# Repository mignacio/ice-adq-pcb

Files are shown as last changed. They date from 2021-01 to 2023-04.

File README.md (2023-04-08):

# ice-adq-pcb

This printed circuit board is a Shield or Poncho for the EDU-CIAA board.
It is a datalogger for internal combustion engines, it has three digital thermocouple readout sensor.
One variable reluctance RPM sensor.
One Narrowband Lambda probe analog interface.
And a resistive oil pressure sensor analog interface.
It trasmits data over bluetooth via an HM-10 BLE module.

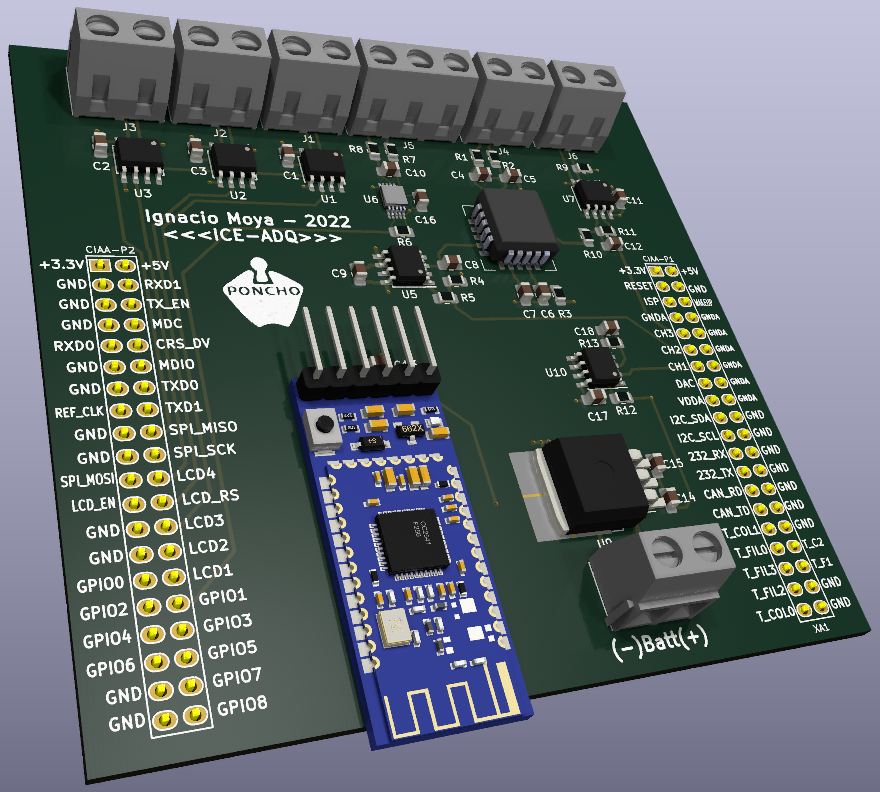
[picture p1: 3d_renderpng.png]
3d-render


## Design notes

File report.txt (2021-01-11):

Info: Backing up file "/home/freesbee/Ponchos/modelos/Basico/sym-lib-table" to file "/home/freesbee/Ponchos/modelos/Basico/rescue-backup/sym-lib-table-2020-12-31-14-45-42".
Info: Backing up file "/home/freesbee/Ponchos/modelos/Basico/basico.sch" to file "/home/freesbee/Ponchos/modelos/Basico/rescue-backup/basico-2020-12-31-14-45-42.sch".
Info: Backing up file "/home/freesbee/Ponchos/modelos/Basico/basico.pro" to file "/home/freesbee/Ponchos/modelos/Basico/rescue-backup/basico-2020-12-31-14-45-42.pro".
Info: Backing up file "/home/freesbee/Ponchos/modelos/Basico/basico-cache.lib" to file "/home/freesbee/Ponchos/modelos/Basico/rescue-backup/basico-cache-2020-12-31-14-45-42.lib".
Info: Backing up file "/home/freesbee/Ponchos/modelos/Basico/basico-rescue.lib" to file "/home/freesbee/Ponchos/modelos/Basico/rescue-backup/basico-rescue-2020-12-31-14-45-42.lib".
Info: Backing up file "/home/freesbee/Ponchos/modelos/Basico/basico-rescue.dcm" to file "/home/freesbee/Ponchos/modelos/Basico/rescue-backup/basico-rescue-2020-12-31-14-45-42.dcm".
Info: Adding library "basico", file "${KIPRJMOD}/lib/basico.lib" to project symbol library table.
Symbol "OSHWA" mapped to symbol library "basico".
Symbol "Logo_Poncho" mapped to symbol library "basico".
Symbol "+3.3V" mapped to symbol library "basico".
Symbol "+5V" mapped to symbol library "basico".
Symbol "PWR_FLAG" mapped to symbol library "basico".
Symbol "+5VP" mapped to symbol library "basico".
Symbol "Conn_Poncho2P_2x_20x2" mapped to symbol library "basico".
Symbol "Conn_Poncho2P_2x_20x2" mapped to symbol library "basico".
Symbol "GND" mapped to symbol library "basico".
Symbol "+3.3VP" mapped to symbol library "basico".
Symbol "+3.3VP" mapped to symbol library "basico".
Symbol "+3.3V" mapped to symbol library "basico".
Symbol "+5VP" mapped to symbol library "basico".
Symbol "+5V" mapped to symbol library "basico".
Symbol "GNDD" mapped to symbol library "basico".
Symbol "GNDD" mapped to symbol library "basico".
Symbol "GND" mapped to symbol library "basico".
Symbol "GNDA" mapped to symbol library "basico".
Symbol "GNDA" mapped to symbol library "basico".
Info: Symbol library table mapping complete!

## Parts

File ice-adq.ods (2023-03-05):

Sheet: ice-adq
Id | Designator | Package | Quantity | Designation | Supplier and ref
1 | XA1 | Conn_Poncho_SinBorde | 1 | Conn_Poncho2P_2x_20x2
2 | G*** | Logo_Poncho | 1 | LOGO
3 | C1,C2,C3,C4,C5,C6,C7,C8,C9,C11,C12,C13,C15,C16,C17,C18 | C_0805_2012Metric_Pad1.15x1.40mm_HandSolder | 16 | 0.01uF
4 | C10 | C_0805_2012Metric_Pad1.15x1.40mm_HandSolder | 1 | 1nF
5 | J1 | TerminalBlock_bornier-2_P5.08mm | 1 | T_AdmisiÃ³n
6 | J2 | TerminalBlock_bornier-2_P5.08mm | 1 | T_Escape
7 | J3 | TerminalBlock_bornier-2_P5.08mm | 1 | T_Aceite
8 | J4 | TerminalBlock_bornier-2_P5.08mm | 1 | Sonda Lambda
9 | J5 | TerminalBlock_bornier-3_P5.08mm | 1 | Sens. Inductivo
10 | J6 | TerminalBlock_bornier-2_P5.08mm | 1 | + PresiÃ³n
11 | J7 | TerminalBlock_bornier-2_P5.08mm | 1 | BATT
12 | R1,R2 | R_0805_2012Metric_Pad1.15x1.40mm_HandSolder | 2 | 100ohm
13 | R3,R6,R7,R8,R13 | R_0805_2012Metric_Pad1.15x1.40mm_HandSolder | 5 | 10k
14 | R4 | R_0805_2012Metric_Pad1.15x1.40mm_HandSolder | 1 | 1.1k
15 | R5 | R_0805_2012Metric_Pad1.15x1.40mm_HandSolder | 1 | 680
16 | R9,R10,R11 | R_0805_2012Metric_Pad1.15x1.40mm_HandSolder | 3 | R_US
17 | U1,U2,U3 | SOIC-8_3.9x4.9mm_P1.27mm | 3 | MAX31855
18 | U5,U7,U10 | SOIC-8_3.9x4.9mm_P1.27mm | 3 | LM358
19 | U6 | UMAX10 | 1 | MAX9924
20 | U4 | PLCC-20 | 1 | LM9044
21 | U9 | SOT-223 | 1 | L7805
22 | R12 | R_0805_2012Metric_Pad1.15x1.40mm_HandSolder | 1 | 39k
23 | C14 | C_0805_2012Metric_Pad1.15x1.40mm_HandSolder | 1 | 0.22uF
24 | U8 | PinHeader_1x06_P2.54mm_Vertical | 1 | hm-10-module

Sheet: BOM
Package | Quantity | Designation | Supplier and ref
C_0805_2012Metric_Pad1.15x1.40mm_HandSolder | 16 | 0.01uF | https://www.digikey.com/product-detail/en/C0805C153K5RAC7800/399-C0805C153K5RAC7800CT-ND/411436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
C_0805_2012Metric_Pad1.15x1.40mm_HandSolder | 1 | 1nF | No se consigue
C_0805_2012Metric_Pad1.15x1.40mm_HandSolder | 1 | 0.22uF | https://www.digikey.com/product-detail/en/C0805C223K5RAC7210/399-C0805C223K5RAC7210CT-ND/12701470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
R_0805_2012Metric_Pad1.15x1.40mm_HandSolder | 2 | 100ohm | https://www.digikey.com/en/products/detail/yageo/AC0805FR-10100RL/14286774
R_0805_2012Metric_Pad1.15x1.40mm_HandSolder | 5 | 10k | https://www.digikey.com/en/products/detail/yageo/AC0805FR-0710KL/2827834
R_0805_2012Metric_Pad1.15x1.40mm_HandSolder | 1 | 1.1k | https://www.digikey.com/en/products/detail/yageo/AC0805FR-071K1L/5896618
R_0805_2012Metric_Pad1.15x1.40mm_HandSolder | 1 | 680 | https://www.digikey.com/en/products/detail/yageo/AC0805FR-07680RL/5896948
R_0805_2012Metric_Pad1.15x1.40mm_HandSolder | 3 | R_US
R_0805_2012Metric_Pad1.15x1.40mm_HandSolder | 1 | 39k | https://www.digikey.com/en/products/detail/yageo/AC0805FR-0739KL/5896800
SOIC-8_3.9x4.9mm_P1.27mm | 3 | MAX31855 | https://www.digikey.com/product-detail/en/MAX31855JASA%2bT/MAX31855JASA%2bTCT-ND/9759999?itemSeq=386971576
SOIC-8_3.9x4.9mm_P1.27mm | 3 | LM358 | https://www.digikey.com/product-detail/en/LM358DR/296-1014-1-ND/404838?itemSeq=386971777
UMAX10 | 1 | MAX9924 | https://www.digikey.com/product-detail/en/MAX9924UAUB%2fV%2b/MAX9924UAUB%2fV%2b-ND/3517308?itemSeq=386971823
PLCC-20 | 1 | LM9044
SOT-223 | 1 | L7805 | https://www.digikey.com/en/products/detail/texas-instruments/LM340T-5-0-LF01/3640765
TerminalBlock_bornier-2_P5.08mm | 1 | T_AdmisiÃ³n
TerminalBlock_bornier-2_P5.08mm | 1 | T_Escape
TerminalBlock_bornier-2_P5.08mm | 1 | T_Aceite
TerminalBlock_bornier-2_P5.08mm | 1 | Sonda Lambda
TerminalBlock_bornier-3_P5.08mm | 1 | Sens. Inductivo
TerminalBlock_bornier-2_P5.08mm | 1 | + PresiÃ³n
TerminalBlock_bornier-2_P5.08mm | 1 | BATT
PinHeader_1x06_P2.54mm_Vertical | 1 | hm-10-module

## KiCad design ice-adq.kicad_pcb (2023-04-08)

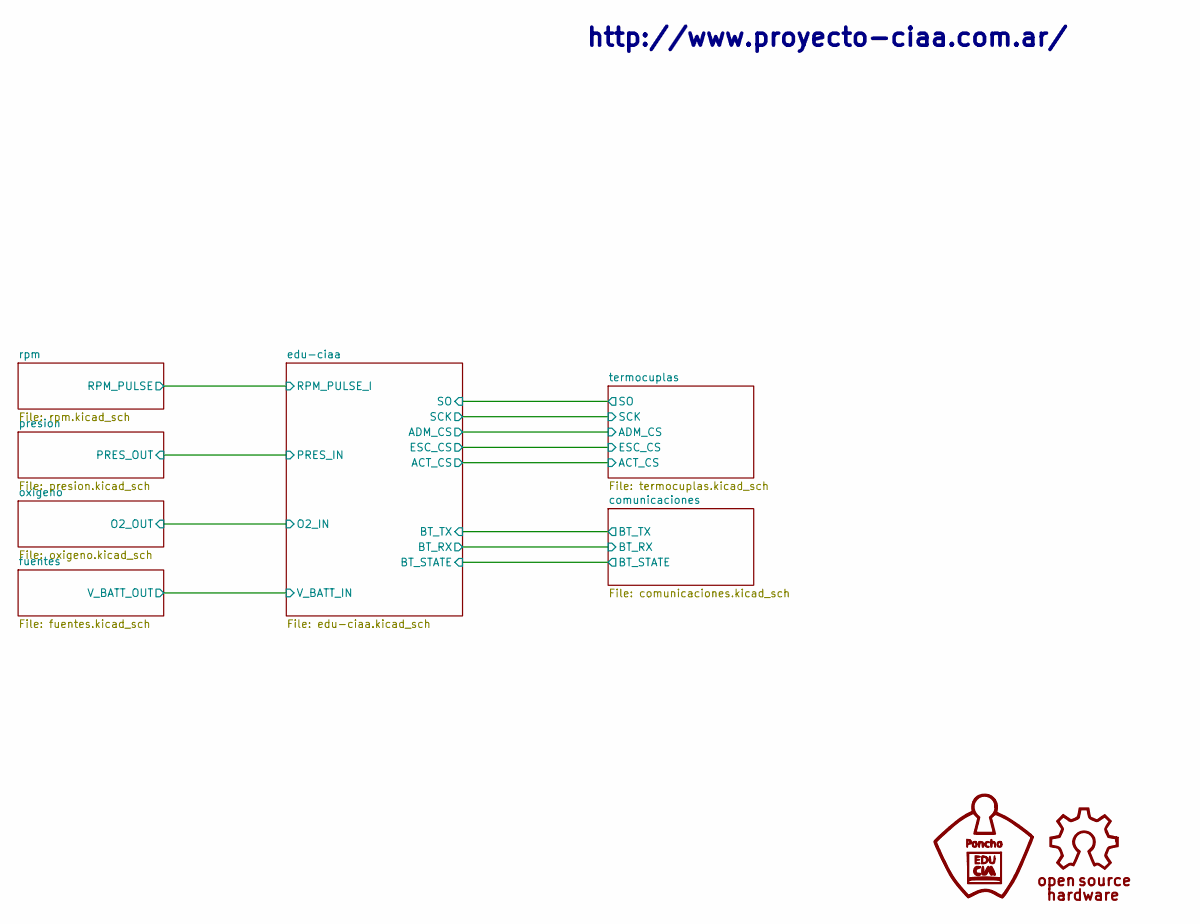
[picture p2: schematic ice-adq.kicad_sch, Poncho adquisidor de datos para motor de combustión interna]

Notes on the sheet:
http://www.proyecto-ciaa.com.ar/

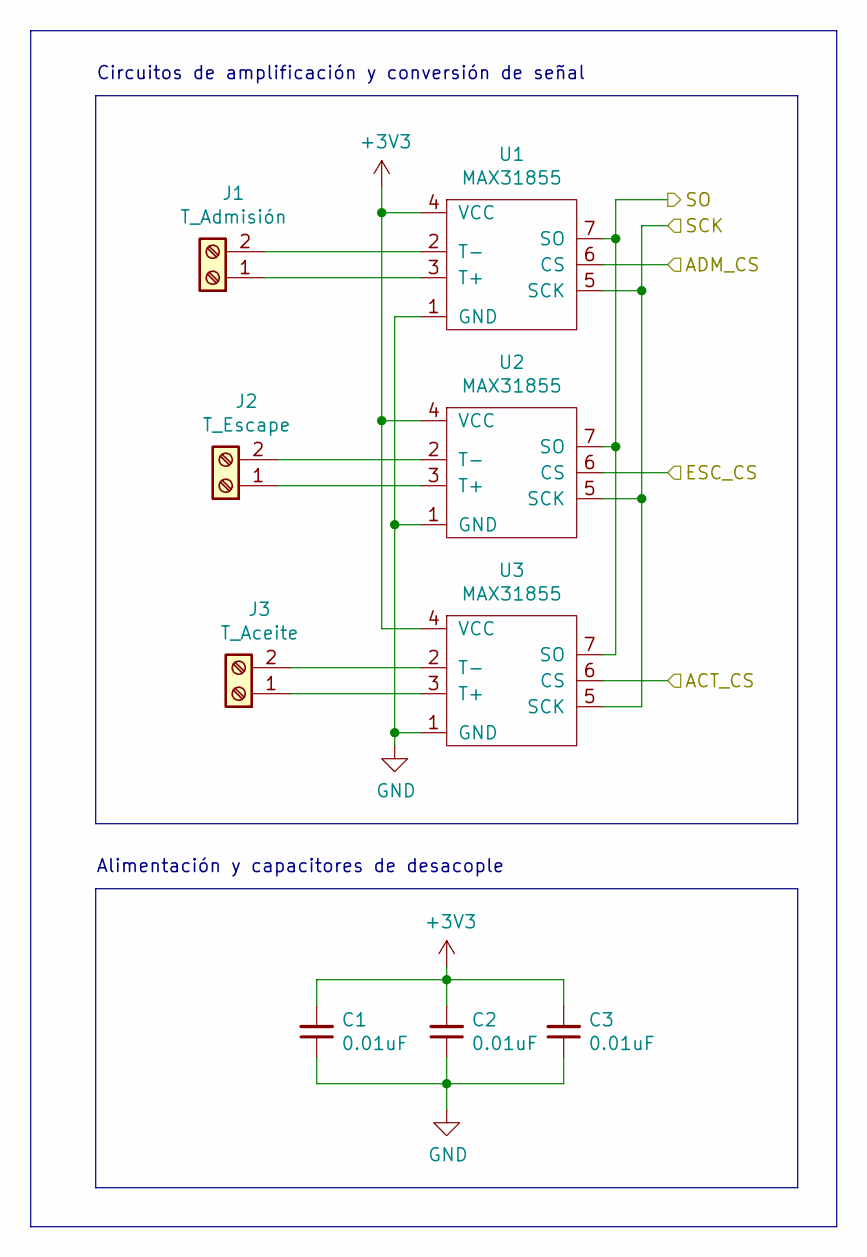
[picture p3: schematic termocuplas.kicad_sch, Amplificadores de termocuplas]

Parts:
C1, C2, C3: 0.01uF; C_0805_2012Metric_Pad1.15x1.40mm_HandSolder
J1: T_Admisión; TerminalBlock_bornier-2_P5.08mm
J2: T_Escape; TerminalBlock_bornier-2_P5.08mm
J3: T_Aceite; TerminalBlock_bornier-2_P5.08mm
U1, U2, U3: MAX31855; SOIC-8_3.9x4.9mm_P1.27mm

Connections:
/edu-ciaa/ACT_CS: U3.6 (CS); also elsewhere on the board
/edu-ciaa/ADM_CS: U1.6 (CS); also elsewhere on the board
/edu-ciaa/ESC_CS: U2.6 (CS); also elsewhere on the board
/edu-ciaa/SCK: U1.5 (SCK), U2.5 (SCK), U3.5 (SCK); also elsewhere on the board
/edu-ciaa/SO: U1.7 (SO), U2.7 (SO), U3.7 (SO); also elsewhere on the board
GND: C1.1, C2.1, C3.1, U1.1 (GND), U2.1 (GND), U3.1 (GND); also elsewhere on the board
unnamed: J1.1, U1.3 (T+)
unnamed: J1.2, U1.2 (T-)
unnamed: J2.1, U2.3 (T+)
unnamed: J2.2, U2.2 (T-)
unnamed: J3.1, U3.3 (T+)
unnamed: J3.2, U3.2 (T-)

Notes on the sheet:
Circuitos de amplificación y conversión de señal
Alimentación y capacitores de desacople

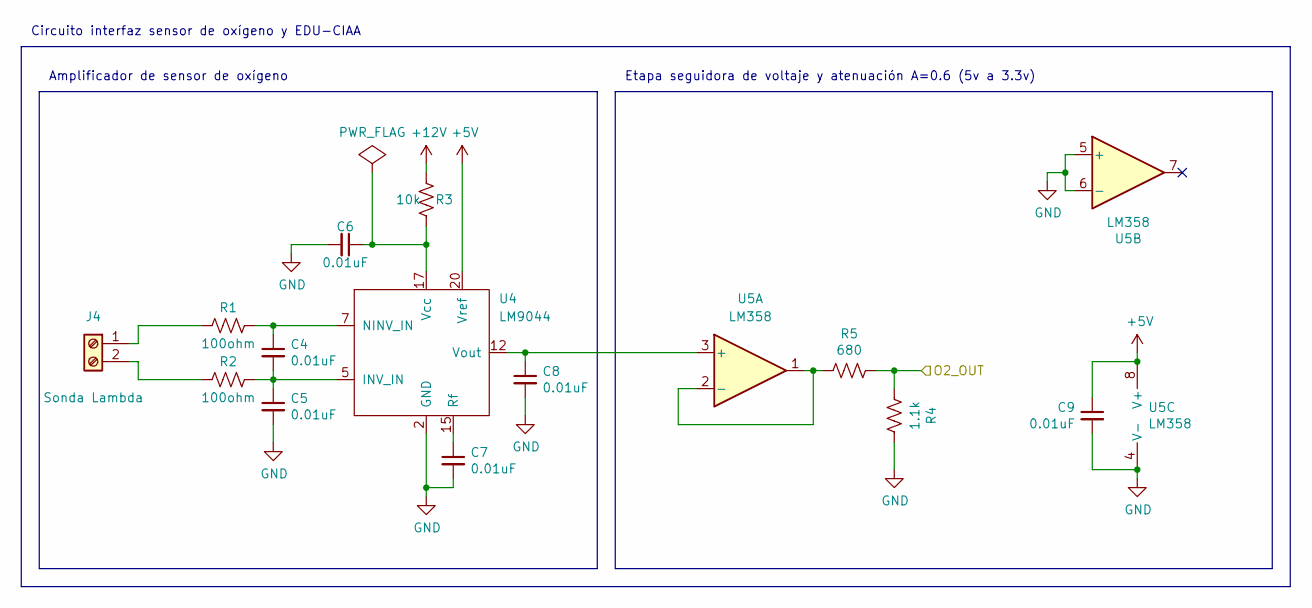
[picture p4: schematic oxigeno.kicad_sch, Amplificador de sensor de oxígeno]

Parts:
C4, C5, C6, C7, C8, C9: 0.01uF; C_0805_2012Metric_Pad1.15x1.40mm_HandSolder
J4: Sonda Lambda; TerminalBlock_bornier-2_P5.08mm
R1, R2: 100ohm; R_0805_2012Metric_Pad1.15x1.40mm_HandSolder
R3: 10k; R_0805_2012Metric_Pad1.15x1.40mm_HandSolder
R4: 1.1k; R_0805_2012Metric_Pad1.15x1.40mm_HandSolder
R5: 680; R_0805_2012Metric_Pad1.15x1.40mm_HandSolder
U4: LM9044; PLCC-20
U5: LM358; SOIC-8_3.9x4.9mm_P1.27mm

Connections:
+5V: C9.1, U4.20 (Vref), U5.8 (V+); also elsewhere on the board
+12V: R3.2; also elsewhere on the board
/edu-ciaa/O2_IN: R4.2, R5.1; also elsewhere on the board
GND: C5.2, C6.2, C7.2, C8.2, C9.2, R4.1, U4.2 (GND), U5.4 (V-), U5.5 (+), U5.6 (-); also elsewhere on the board
unnamed: C4.1, R1.1, U4.7 (NINV_IN)
unnamed: C4.2, C5.1, R2.1, U4.5 (INV_IN)
unnamed: C6.1, R3.1, U4.17 (Vcc)
unnamed: C7.1, U4.15 (Rf)
unnamed: C8.1, U4.12 (Vout), U5.3 (+)
unnamed: J4.1, R1.2
unnamed: J4.2, R2.2
unnamed: R5.2, U5.1, U5.2 (-)

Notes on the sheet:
Etapa seguidora de voltaje y atenuación A=0.6 (5v a 3.3v)
Amplificador de sensor de oxígeno
Circuito interfaz sensor de oxígeno y EDU-CIAA

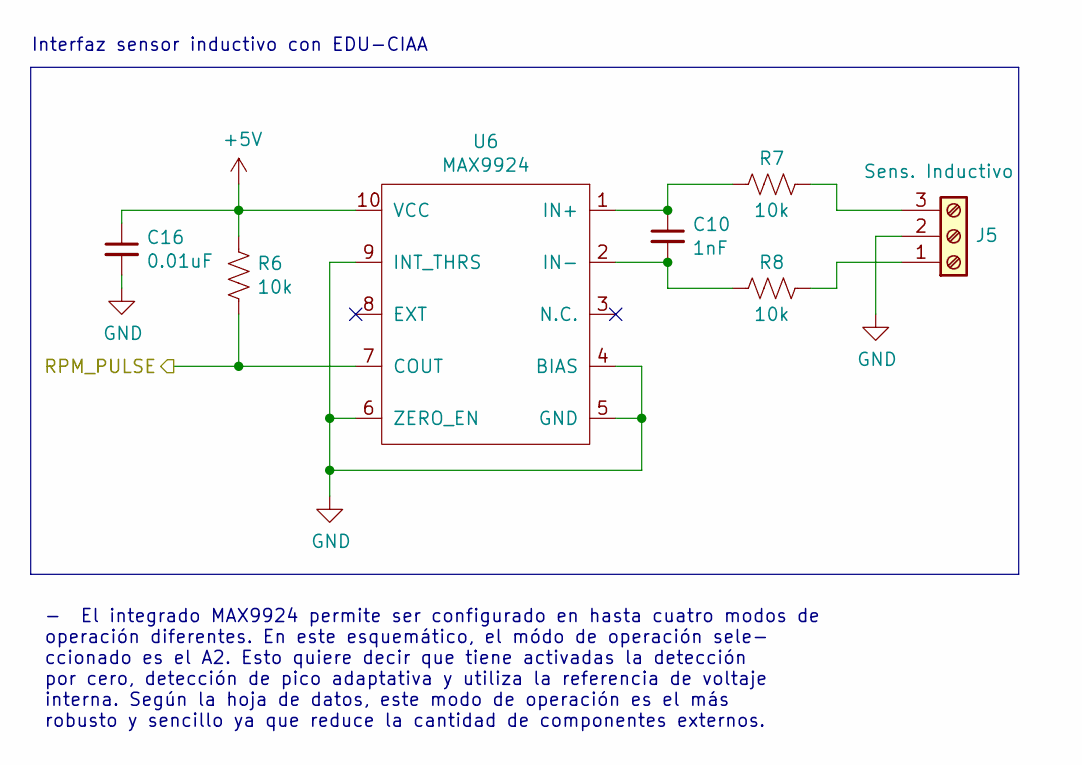
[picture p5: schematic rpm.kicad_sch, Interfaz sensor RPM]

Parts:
C10: 1nF; C_0805_2012Metric_Pad1.15x1.40mm_HandSolder
C16: 0.01uF; C_0805_2012Metric_Pad1.15x1.40mm_HandSolder
J5: Sens. Inductivo; TerminalBlock_bornier-3_P5.08mm
R6, R7, R8: 10k; R_0805_2012Metric_Pad1.15x1.40mm_HandSolder
U6: MAX9924; UMAX10

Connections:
+5V: C16.1, R6.1, U6.10 (VCC); also elsewhere on the board
/rpm/RPM_PULSE: R6.2, U6.7 (COUT); also elsewhere on the board
GND: C16.2, J5.2, U6.4 (BIAS), U6.5 (GND), U6.6 (ZERO_EN), U6.9 (INT_THRS); also elsewhere on the board
unnamed: C10.1, R7.2, U6.1 (IN+)
unnamed: C10.2, R8.2, U6.2 (IN-)
unnamed: J5.1, R8.1
unnamed: J5.3, R7.1

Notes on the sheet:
- El integrado MAX9924 permite ser configurado en hasta cuatro modos de operación diferentes. En este esquemático, el módo de operación sele- ccionado es el A2. Esto quiere decir que tiene activadas la detección por cero, detección de pico adaptativa y utiliza la referencia de voltaje interna. Segú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
Interfaz sensor inductivo con EDU-CIAA

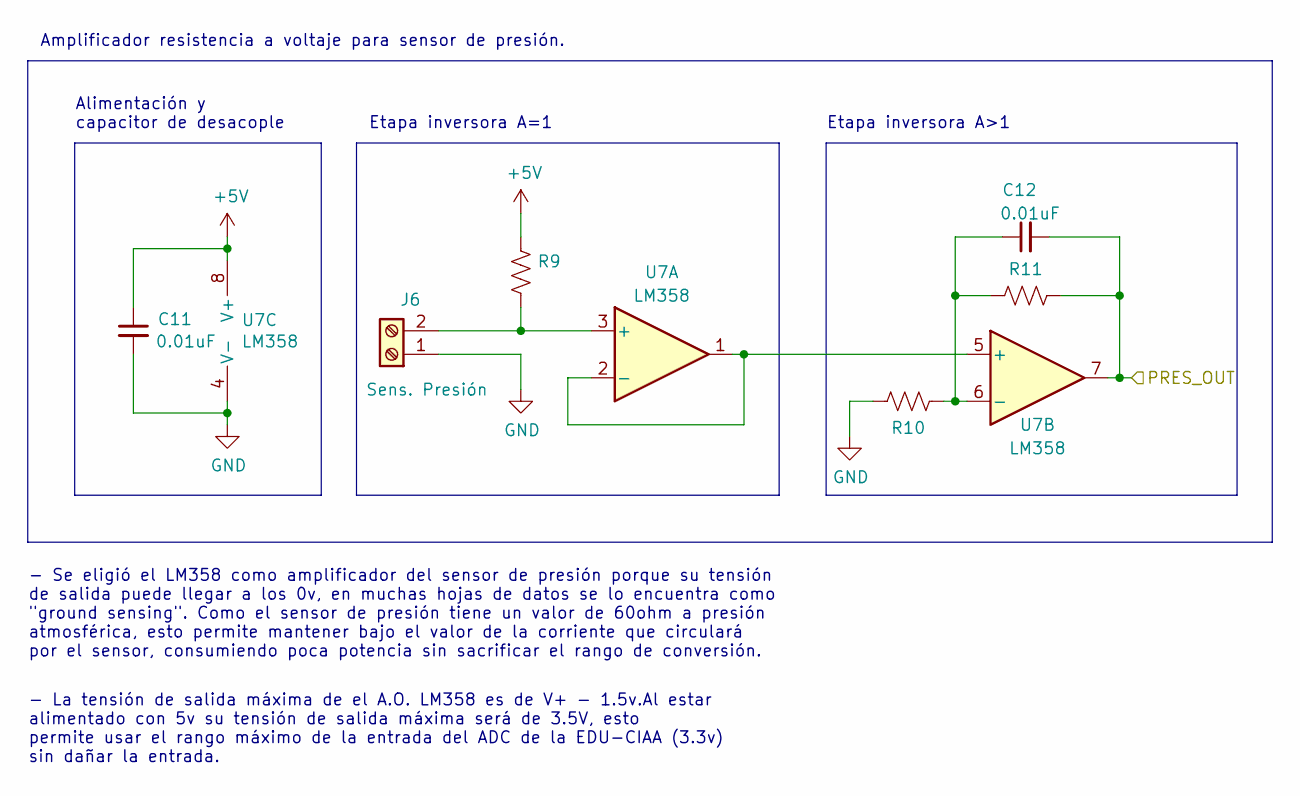
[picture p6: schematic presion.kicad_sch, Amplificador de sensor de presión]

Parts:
C11, C12: 0.01uF; C_0805_2012Metric_Pad1.15x1.40mm_HandSolder
J6: Sens. Presión; TerminalBlock_bornier-2_P5.08mm
R9, R10, R11: R_US; R_0805_2012Metric_Pad1.15x1.40mm_HandSolder
U7: LM358; SOIC-8_3.9x4.9mm_P1.27mm

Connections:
+5V: C11.1, R9.1, U7.8 (V+); also elsewhere on the board
/edu-ciaa/PRES_IN: C12.2, R11.1, U7.7; also elsewhere on the board
GND: C11.2, J6.1, R10.1, U7.4 (V-); also elsewhere on the board
unnamed: C12.1, R10.2, R11.2, U7.6 (-)
unnamed: J6.2, R9.2, U7.3 (+)
unnamed: U7.1, U7.2 (-), U7.5 (+)

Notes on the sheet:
Etapa inversora A>1
Amplificador resistencia a voltaje para sensor de presión.
Etapa inversora A=1
- Se eligió el LM358 como amplificador del sensor de presión porque su tensión de salida puede llegar a los 0v, en muchas hojas de datos se lo encuentra como "ground sensing". Como el sensor de presión tiene un valor de 60ohm a presión atmosférica, esto permite mantener bajo el valor de la corrient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
- La tensión de salida máxima de el A.O. LM358 es de V+ - 1.5v.Al estar alimentado con 5v su tensión de salida máxima será de 3.5V, esto permite usar el rango máximo de la entrada del ADC de la EDU-CIAA (3.3v) sin dañar la entrada.
Alimentación y capacitor de desacople

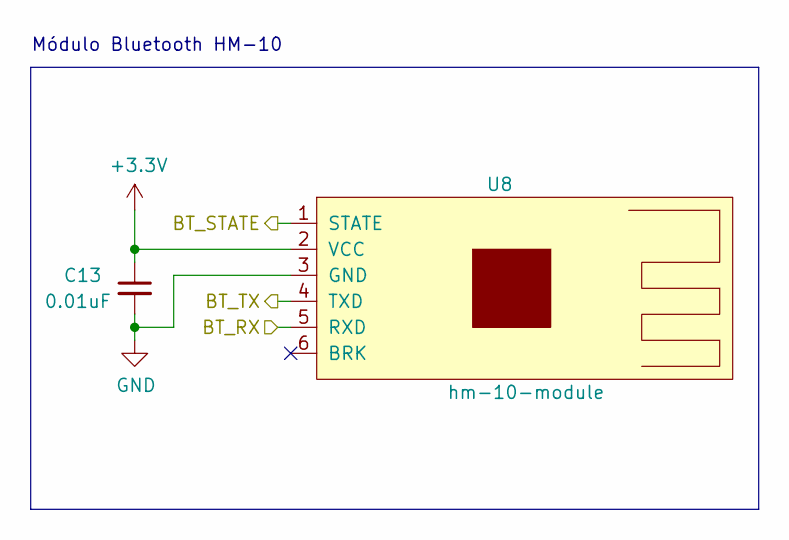
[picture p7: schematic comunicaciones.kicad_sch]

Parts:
C13: 0.01uF; C_0805_2012Metric_Pad1.15x1.40mm_HandSolder
U8: hm-10-module

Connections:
/comunicaciones/BT_RX: U8.5 (RXD); also elsewhere on the board
/comunicaciones/BT_STATE: U8.1 (STATE); also elsewhere on the board
/comunicaciones/BT_TX: U8.4 (TXD); also elsewhere on the board
GND: C13.2, U8.3 (GND); also elsewhere on the board

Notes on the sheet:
Módulo Bluetooth HM-10

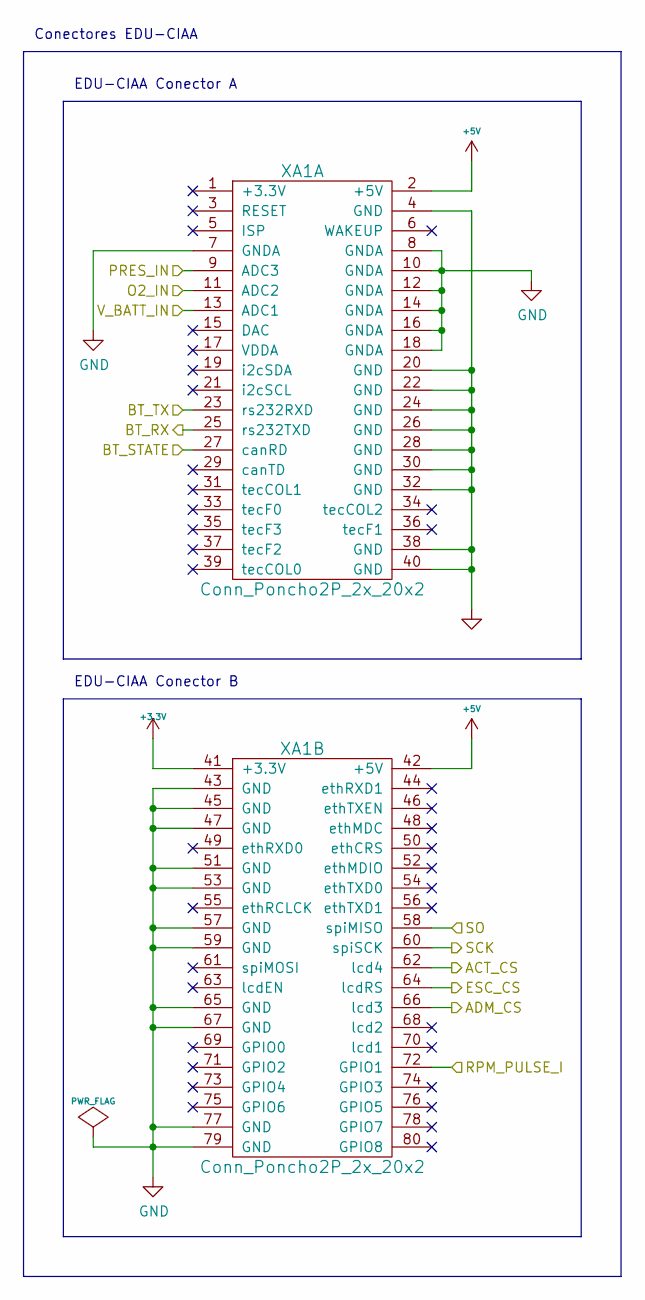
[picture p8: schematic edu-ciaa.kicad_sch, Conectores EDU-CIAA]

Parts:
XA1: Conn_Poncho2P_2x_20x2; Conn_Poncho_SinBorde; Digikey# 952-1387-ND

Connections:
+5V: XA1.2 (+5V), XA1.42 (+5V); also elsewhere on the board
/comunicaciones/BT_RX: XA1.25 (rs232TXD); also elsewhere on the board
/comunicaciones/BT_STATE: XA1.27 (canRD); also elsewhere on the board
/comunicaciones/BT_TX: XA1.23 (rs232RXD); also elsewhere on the board
/edu-ciaa/ACT_CS: XA1.62 (lcd4); also elsewhere on the board
/edu-ciaa/ADM_CS: XA1.66 (lcd3); also elsewhere on the board
/edu-ciaa/ESC_CS: XA1.64 (lcdRS); also elsewhere on the board
/edu-ciaa/O2_IN: XA1.11 (ADC2); also elsewhere on the board
/edu-ciaa/PRES_IN: XA1.9 (ADC3); also elsewhere on the board
/edu-ciaa/SCK: XA1.60 (spiSCK); also elsewhere on the board
/edu-ciaa/SO: XA1.58 (spiMISO); also elsewhere on the board
/edu-ciaa/V_BATT_IN: XA1.13 (ADC1); also elsewhere on the board
/rpm/RPM_PULSE: XA1.72 (GPIO1); also elsewhere on the board
GND: XA1.4 (GND), XA1.7 (GNDA), XA1.8 (GNDA), XA1.10 (GNDA), XA1.12 (GNDA), XA1.14 (GNDA), XA1.16 (GNDA), XA1.18 (GNDA), XA1.20 (GND), XA1.22 (GND), XA1.24 (GND), XA1.26 (GND), XA1.28 (GND), XA1.30 (GND), XA1.32 (GND), XA1.38 (GND), XA1.40 (GND), XA1.43 (GND), XA1.45 (GND), XA1.47 (GND), XA1.51 (GND), XA1.53 (GND), XA1.57 (GND), XA1.59 (GND), XA1.65 (GND), XA1.67 (GND), XA1.77 (GND), XA1.79 (GND); also elsewhere on the board

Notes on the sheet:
EDU-CIAA Conector A
EDU-CIAA Conector B
Conectores EDU-CIAA

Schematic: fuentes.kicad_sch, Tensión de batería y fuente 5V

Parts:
C14: 0.22uF; C_0805_2012Metric_Pad1.15x1.40mm_HandSolder
C15, C17, C18: 0.01uF; C_0805_2012Metric_Pad1.15x1.40mm_HandSolder
J7: BATT; TerminalBlock_bornier-2_P5.08mm
R12: 39k; R_0805_2012Metric_Pad1.15x1.40mm_HandSolder
R13: 10k; R_0805_2012Metric_Pad1.15x1.40mm_HandSolder
U9: L7805; TO-263-3_TabPin2
U10: LM358; SOIC-8_3.9x4.9mm_P1.27mm

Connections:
+5V: C15.1, C17.1, U9.3 (OUT), U10.8 (V+); also elsewhere on the board
+12V: C14.1, J7.1, R12.1, U9.1 (IN); also elsewhere on the board
/edu-ciaa/V_BATT_IN: U10.1, U10.2 (-); also elsewhere on the board
GND: C14.2, C15.2, C17.2, C18.2, J7.2, R13.2, U9.2 (GND), U10.4 (V-), U10.5 (+), U10.6 (-); also elsewhere on the board
unnamed: C18.1, R12.2, R13.1, U10.3 (+)

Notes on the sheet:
Conector batería y fuente 5 voltios.
Interfaz tensión de batería y ADC

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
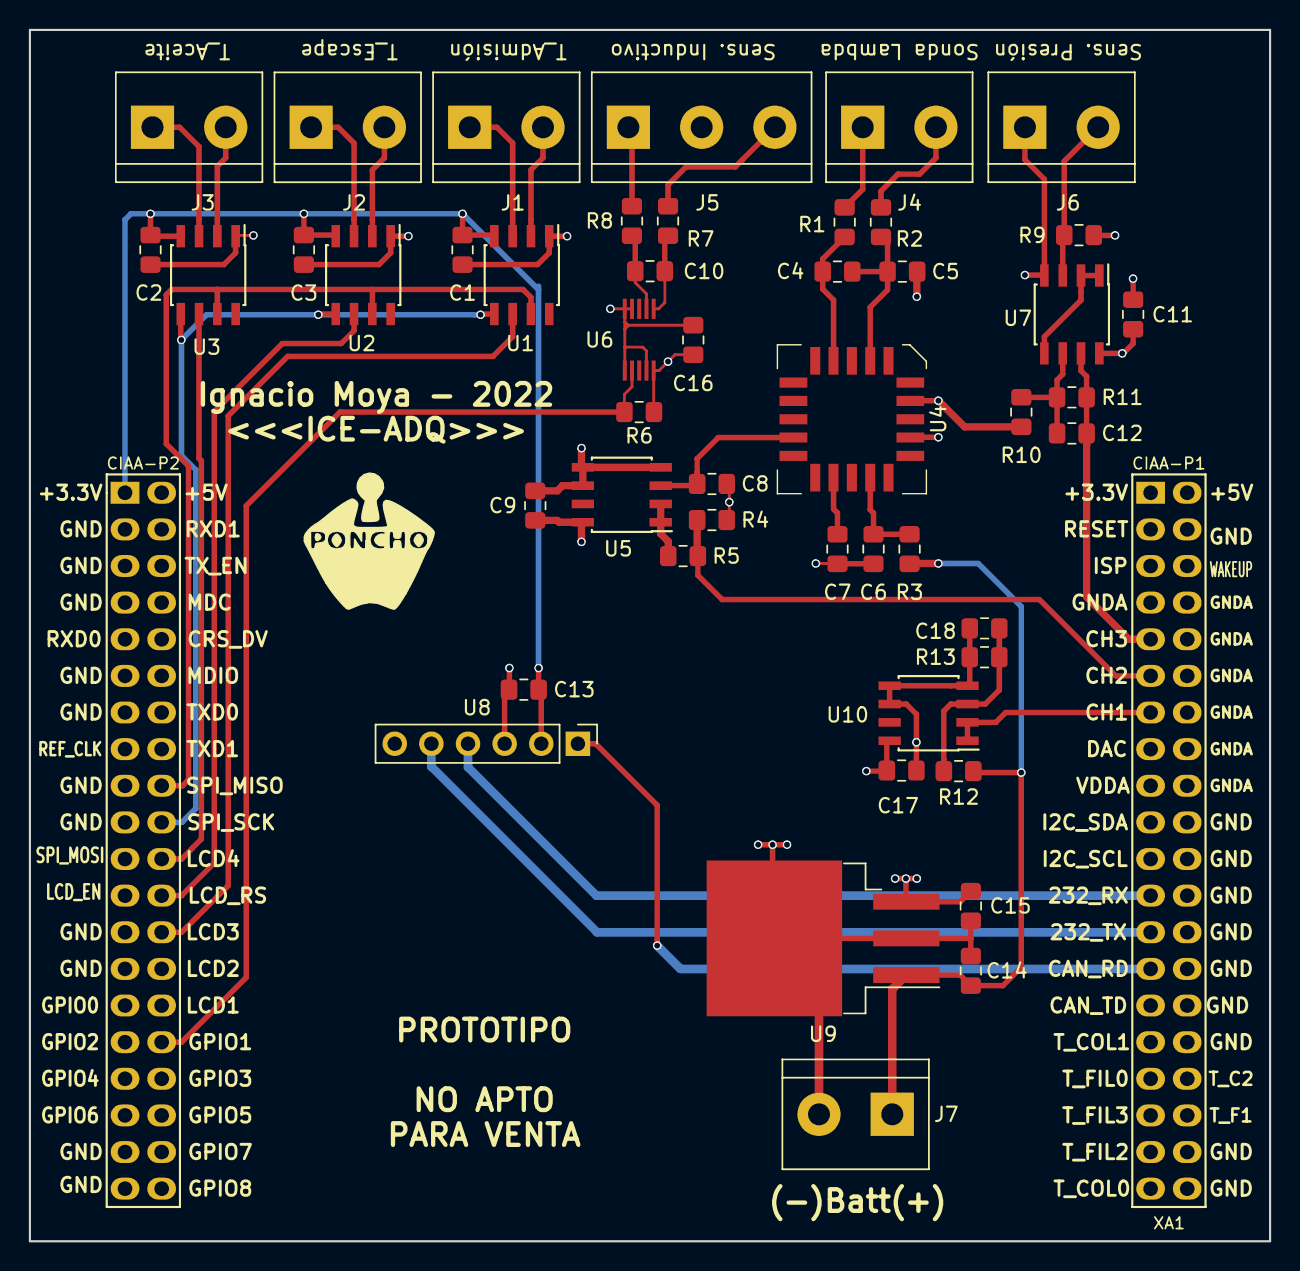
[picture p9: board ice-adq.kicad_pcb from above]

Board: 4 copper layers, 86.0 x 84.0 mm, 49 parts (0 on the bottom side), 38 nets.

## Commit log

2021-01-11 segundo commit
    [basico-2020-12-31-14-45-42.sch, basico-2020-12-31-14-48-33.sch, basico-2020-12-31-14-52-55.sch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]
2021-02-07 Terminado el esquemático para los amplificadores de termocuplas
    [comunicaciones.sch, ice-adq.sch, oxigeno.sch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]
2021-02-13 avances en el esquematico del amplificador de sonda lambda
    [oxigeno.sch, termocuplas.sch]
2021-12-11 Primer rev esquematicos RPM y comunicaciones
    [MAX9924UAUB+.STEP, comunicaciones.sch, ice-adq.sch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]
2021-12-18 Esquematicos mayormente terminados, falta sub-hoja edu ciaa, fuentes de alimentacion y poner valores a los componentes
    [comunicaciones.sch, ice-adq.sch, oxigeno.sch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]
2021-12-18 Se agrego esquematico de fuentes y se corrigieron errores de ERC
    [comunicaciones.sch, edu-ciaa.sch, fuentes.sch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]
2021-12-19 Correccion de errores y se designaron huellas a casi todos los componentes
    [comunicaciones.sch, edu-ciaa.sch, fuentes.sch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]
2021-12-19 Ubicación de componentes y algo de ruteado
    [edu-ciaa.sch, ice-adq.kicad_pcb, oxigeno.sch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]
2021-12-29 Se cambio pack de 7805 y de 9044
    [edu-ciaa.sch, fuentes.sch, ice-adq.kicad_pcb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]
2022-01-02 Ruteado de circuito de medicion de bateria
    [edu-ciaa.sch, fuentes.sch, ice-adq.kicad_pcb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]
2022-01-02 Se agregaron modelos 3d faltantes
    [comunicaciones.sch, ice-adq.kicad_pcb]
2023-03-05 Comitee cambios que estaban hechos.
    [comunicaciones.kicad_sch, comunicaciones.sch, edu-ciaa.kicad_sch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]
2023-03-05 Migración a kicad 7.0.
2023-04-08 Actualizacion a kicad 7, seleccion de ganancia de la etapa de amplificacion de presion de aceite.
    [comunicaciones.kicad_sch, edu-ciaa.kicad_sch, fuentes.kicad_sch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]
2023-04-08 Cambios en plano de presion y agregue render en 3D de la placa.
    [presion.kicad_sch]
2023-04-08 Agregue un readme y render 3D de la placa.
2023-04-15 Agregué datos sobre función transferencia del circuito de presión.
    [presion.kicad_sch]
